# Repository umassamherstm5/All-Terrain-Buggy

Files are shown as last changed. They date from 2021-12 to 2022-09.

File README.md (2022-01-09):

# All-Terrain-Buggy
The All-Terrain Buggy is a buggy that goes on most if not all terrains. 

It is a 6-wheeled AWD remote controlled vehicle. The motors are driven by the DRV8871 motor drivers. 
The buggy is controlled via a FlySky remote that feeds PWM signals into an Adafruit Feather 328P MCU.  

This project contains the firmware for the Feather 328P and all KiCad files for the buggy's custom PCB.

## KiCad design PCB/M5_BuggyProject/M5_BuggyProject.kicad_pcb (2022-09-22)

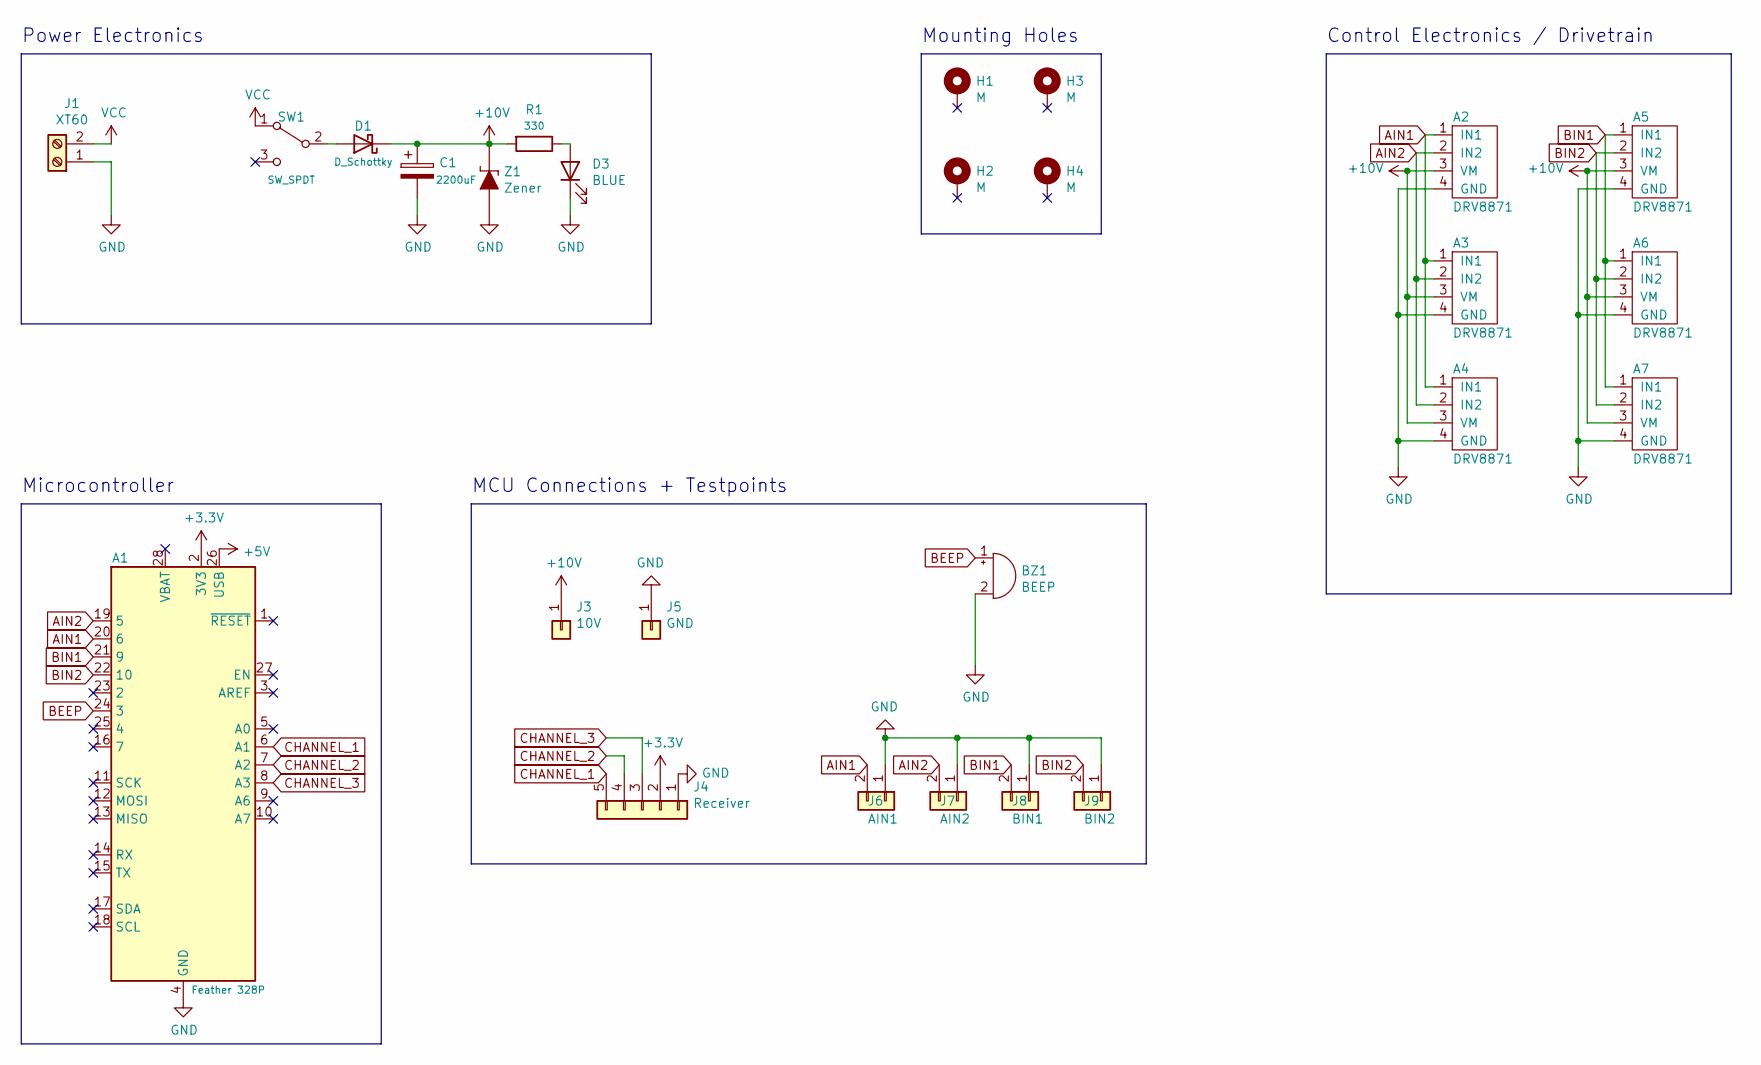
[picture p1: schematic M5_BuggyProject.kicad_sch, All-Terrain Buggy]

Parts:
A1: Feather 328P; Adafruit_Feather
A2, A3, A4, A5, A6, A7: DRV8871; PinSocket_1x04_P2.54mm_Vertical
BZ1: BEEP; Buzzer_12x9.5RM7.6
C1: 2200uF; CP_Radial_D10.0mm_P5.00mm
D1: D_Schottky; TO-220-2_Vertical
D3: BLUE; LED_1206_3216Metric
H1, H2, H3, H4: M; MountingHole_4.3mm_M4_Pad_Via
J1: XT60; AMASS_XT60-M_1x02_P7.20mm_Vertical
J3: 10V; TestPoint_Plated_Hole_D5.0mm
J4: Receiver; PinSocket_1x05_P2.54mm_Vertical
J5: GND; TestPoint_Plated_Hole_D5.0mm
J6: AIN1; PinSocket_1x02_P2.54mm_Vertical
J7: AIN2; PinSocket_1x02_P2.54mm_Vertical
J8: BIN1; PinSocket_1x02_P2.54mm_Vertical
J9: BIN2; PinSocket_1x02_P2.54mm_Vertical
R1: 330; R_1206_3216Metric
SW1: SW_SPDT; 1101M2S3CQE2
Z1: Zener; DO-214AC; MPN 1N5231BTR; Digi-Key_PN 1N5231BFSCT-ND

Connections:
+3V3: A1.2 (3V3), J4.2
+5V: A1.26 (USB)
+10V: A2.3 (VM), A3.3 (VM), A4.3 (VM), A5.3 (VM), A6.3 (VM), A7.3 (VM), C1.1, D1.1 (K), J3.1, R1.2, Z1.K
AIN1: A1.20 (6), A2.1 (IN1), A3.1 (IN1), A4.1 (IN1), J6.2
AIN2: A1.19 (5), A2.2 (IN2), A3.2 (IN2), A4.2 (IN2), J7.2
BEEP: A1.24 (3), BZ1.1 (-)
BIN1: A1.21 (9), A5.1 (IN1), A6.1 (IN1), A7.1 (IN1), J8.2
BIN2: A1.22 (10), A5.2 (IN2), A6.2 (IN2), A7.2 (IN2), J9.2
CHANNEL_1: A1.6 (A1), J4.5
CHANNEL_2: A1.7 (A2), J4.4
CHANNEL_3: A1.8 (A3), J4.3
GND: A1.4 (GND), A2.4 (GND), A3.4 (GND), A4.4 (GND), A5.4 (GND), A6.4 (GND), A7.4 (GND), BZ1.2 (+), C1.2, D3.1 (K), J1.1, J4.1, J5.1, J6.1, J7.1, J8.1, J9.1, Z1.A
unnamed: D1.2 (A), SW1.2 (B)
unnamed: D3.2 (A), R1.1
VCC: J1.2, SW1.1 (A)

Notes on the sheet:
MCU Connections + Testpoints
Control Electronics / Drivetrain
Power Electronics
Mounting Holes
Microcontroller

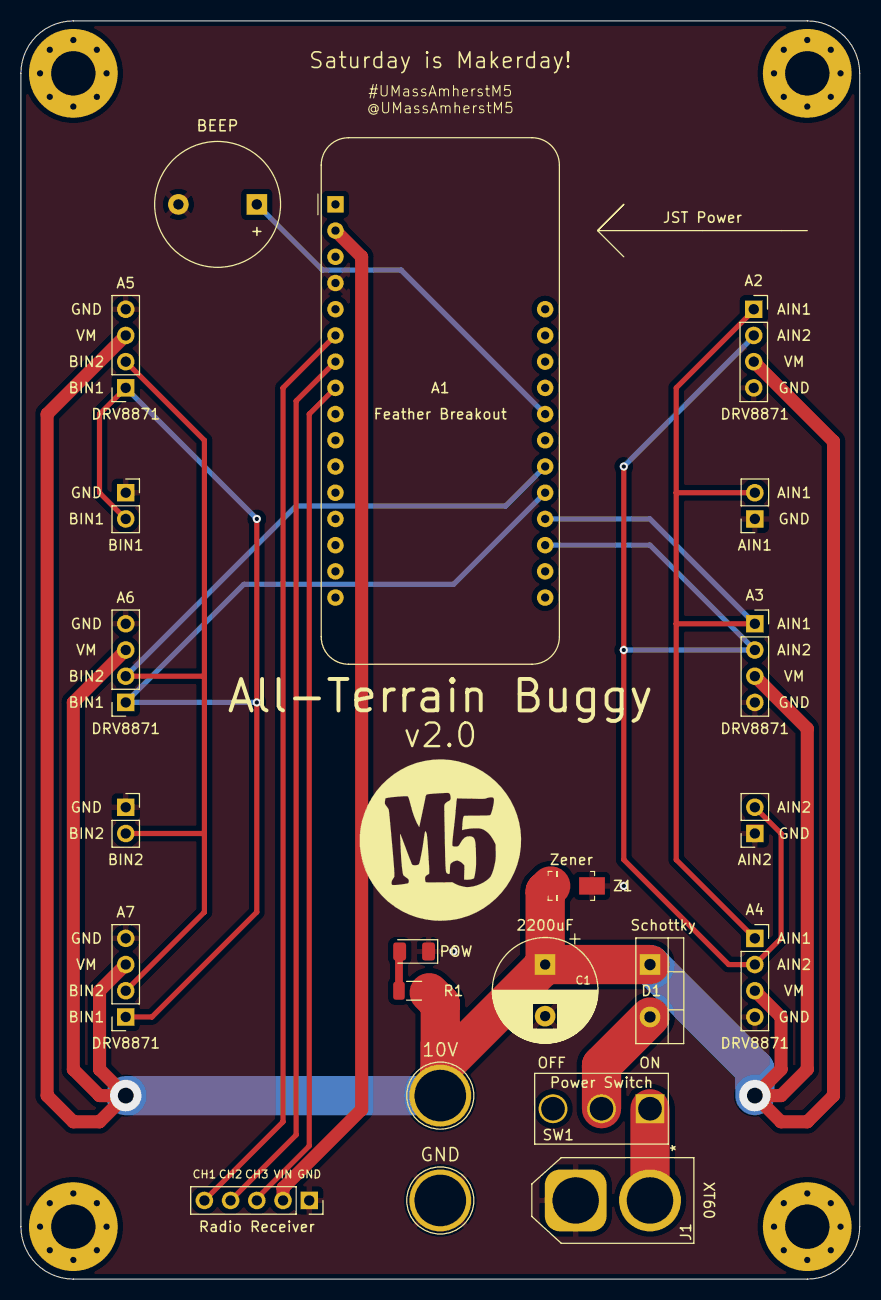
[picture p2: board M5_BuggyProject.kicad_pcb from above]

Board: 2 copper layers, 81.3 x 121.9 mm, 26 parts (0 on the bottom side), 14 nets.

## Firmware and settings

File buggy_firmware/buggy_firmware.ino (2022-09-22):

/*
 * All-Terrain Buggy
 * Firmware for interfacing with buggy and remote control 
 * Authors: Akshat Sahay, Chris Caron, Sebastian Armstrong 
 */

/*
 * FlySky FS-GT
 * ------------
 * The FlySky FS-GT is a radio receiver module which pairs to a FlySky hobbyist controller. 
 * 
 * We connect this receiver to our Feather 328P and read the pulses on different channels using the pulseIn function. 
 * CHANNEL_1 refers to the left joystick's vertical motion. 
 * CHANNEL_2 refers to the right joystick's horizontal motion. 
 * CHANNEL_3 refers to the right pot 
 */

/* pin assignments for FlySky receiver signals */
#define CHANNEL_1 A1 // controller CH2  
#define CHANNEL_2 A2 // controller CH4
#define CHANNEL_3 A3 // controller flipswitch L

/*
 * DRV8871 Motor Driver 
 * --------------------
 * The DRV8871 is a brushed DC motor driver. Two logic inputs control 4 N-channel MOFSETs for bidirectional control. 
 * The inputs can be either HIGH/LOW or PWM (we use PWM and LOW) to control motor speed and direction. 
 * Setting both inputs to LOW activates a low-power deep sleep mode. This will help us conserve battery life. 
 * 
 * For ease of control, we connect each of the 3 motors on either side of the buggy together. 
 * This allows us to use only 4 pins on the Arduino instead of 12 (2 for each motor)
 * This also makes turning easy, as we simply slow down a side to turn in either direction. 
 * In the code, we refer to A as the right side and B as the left side. 
 * 
 * All inputs are PWM-capable pins 
 * AIN1 refers to input 1 for the right side. 
 * AIN2 refers to input 2 for the right side.
 * BIN1 refers to input 1 for the left side. 
 * BIN2 refers to input 2 for the left side. 
 */

/* pin assignments for driver control signals */
#define AIN1 6
#define AIN2 5 
#define BIN1 9
#define BIN2 10 

/*
 * We use pulseIn to read the pulse durations on CHANNEL_1 and CHANNEL_2. 
 * pulseIn detects a change on a pin (LOW->HIGH/HIGH->LOW). 
 * It measures the duration of the change and returns the duration in microseconds. 
 * 
 * The receiver pulses have default durations of about 1450us for CHANNEL_1 and 1475us for CHANNEL_2.  
 * Any shorter or longer pulses mean the joysticks are being used, and the buggy needs to perform an action. 
 * 
 * The threshold values are to check for the default durations: they act as a "deadzone" when the joysticks 
 * are in their central position. The car only performs actions when the durations are more than the 
 * "deadzone" values. 
 * 
 * We organise the buggy's action into 5 modes: STOP, FORWARD, BACKWARD, LEFT and RIGHT. 
 * Speed and vertical direction are controlled by the left joystick (sig1, CHANNEL_1). 
 * Horizontal direction is controlled by the right joystick (sig2, CHANNEL_2). 
 * 
 * STOP, FORWARD and BACKWARD are simple: the car stops, goes forward or backward. 
 * LEFT and RIGHT are a little more complex: in these modes the car goes in the direction specified, 
 * but the forward and backward motion is controlled within these conditions. 
*/

/* thresholds for signal values, used for identifying action and speed */
#define SIG_HIGH_ACC 1490
#define SIG_LOW_ACC 1410

#define SIG_HIGH_STEER 1515
#define SIG_LOW_STEER 1435

#define SIG_MAX_ACC 1850
#define SIG_MIN_ACC 1100

#define SIG_MAX_STEER 1950
#define SIG_MIN_STEER 1050

#define DEBUG 0  

/* variables for incoming pulse widths from CHANNEL_1 and CHANNEL_2 respectively */
int sig1 = 0; // CHANNEL_1 value
int sig2 = 0; // CHANNEL_2 value
int beep = 0; // to BEEP or not

/* variables for speed of either side */
int a_speed = 0; // speed of right side
int b_speed = 0; // speed of left side
int offset  = 0; // speed difference for turning

/* pins for debugging and BEEP */
#define BEEP 3
#define CONFIG_R A6
#define CONFIG_L A7

/*
 * Function: setup
 * ---------------
 * Runs once at the beginning of the code (when the buggy powers up or resets). 
 * Sets all required pin modes and begins the serial module. 
 * 
 * returns: none 
 */
void setup() {
  // set RC channels to INPUT
  pinMode(CHANNEL_1, INPUT); 
  pinMode(CHANNEL_2, INPUT); 

  // set driver pins to OUTPUT
  pinMode(AIN1, OUTPUT); 
  pinMode(AIN2, OUTPUT); 
  pinMode(BIN1, OUTPUT); 
  pinMode(BIN2, OUTPUT); 

  // set debugging pins to OUTPUT
  pinMode(BEEP, OUTPUT);
  pinMode(CONFIG_L, OUTPUT);
  pinMode(CONFIG_R, OUTPUT);

  // start serial port
  Serial.begin(9600);  
}

/*
 * Function: loop
 * --------------
 * Runs every clock cycle of the ATMEGA328P (8MHz frequency). 
 * Collects pulse values from the FlySky FS-GT receiver and uses them to drive the buggy. 
 * 
 * returns: none 
 */
void loop() {
  // get signal values from receiver 
  sig1 = pulseIn(CHANNEL_1, HIGH);
  sig2 = pulseIn(CHANNEL_2, HIGH);

  if(DEBUG == 1) {
    // print signal values
    Serial.print("Signals: "); 
    Serial.print(sig1);
    Serial.print(" ");
    Serial.println(sig2);    
  }
  
  if(((sig1 < SIG_HIGH_ACC) && (sig1 > SIG_LOW_ACC)) && ((sig2 < SIG_HIGH_STEER) && (sig2 > SIG_LOW_STEER))) {
    // both signals are OFF, state: STOP
    Serial.println("OFF"); 

    // set drivers to STOP mode 
    digitalWrite(AIN1, LOW);
    digitalWrite(AIN2, LOW); 
    digitalWrite(BIN1, LOW);
    digitalWrite(BIN2, LOW); 
  }

  else if((sig1 > SIG_HIGH_ACC) && ((sig2 < SIG_HIGH_STEER) && (sig2 > SIG_LOW_STEER))) {
    // sig1 is ON, sig2 is OFF, state: FORWARD
    Serial.println("FORWARD"); 

    // limit sig1 values for speed
    if(sig1 > SIG_MAX_ACC) sig1 = SIG_MAX_ACC; 

    // get speed proportional to sig1 in FORWARD state
    // the higher the sig1 val, the higher the speed
    a_speed = map(sig1, SIG_HIGH_ACC, SIG_MAX_ACC, 0, 255);  


    // set drivers to FORWARD mode
    analogWrite(AIN1, a_speed);
    digitalWrite(AIN2, LOW); 
    analogWrite(BIN1, a_speed);
    digitalWrite(BIN2, LOW); 
  }

  else if((sig1 < SIG_LOW_ACC) && ((sig2 < SIG_HIGH_STEER) && (sig2 > SIG_LOW_STEER))) {
    // sig1 is -ON, sig2 is OFF, state: BACKWARD
    Serial.println("BACKWARD"); 

    // limit sig1 values for speed
    if(sig1 < SIG_MIN_ACC) sig1 = SIG_MIN_ACC;

    // get speed proportional to sig1 in BACKWARD state
    // the lower the sig1 val, the higher the speed
    a_speed = map(sig1, SIG_LOW_ACC, SIG_MIN_ACC, 0, 255); 

    // set driver to COUNTER-CLOCKWISE mode
    digitalWrite(AIN1, LOW);
    analogWrite(AIN2, a_speed);
    digitalWrite(BIN1, LOW);
    analogWrite(BIN2, a_speed);       
  }

  else if((sig2 < SIG_LOW_STEER) && sig2 > 0) {
    // sig1 is either ON or OFF, sig2 is ON, state: RIGHT
    Serial.print("RIGHT "); 

    if(sig1 > SIG_HIGH_ACC) {
      Serial.println("FORWARD");  

      // limit sig1 values for speed
      if(sig1 > SIG_MAX_ACC) sig1 = SIG_MAX_ACC; 
      // limit sig2 values for speed
      if(sig2 < SIG_MIN_STEER) sig2 = SIG_MIN_STEER;
  
      b_speed = map(sig1, SIG_HIGH_ACC, SIG_MAX_ACC, 0, 255); 
      offset  = map(sig2, SIG_LOW_STEER, SIG_MIN_STEER, 0, b_speed/2); 
      // to go RIGHT, left side faster than right side 
      a_speed = b_speed - offset; 
      
      // set driver to CLOCKWISE mode
      analogWrite(AIN1, a_speed);
      digitalWrite(AIN2, LOW); 
      analogWrite(BIN1, b_speed);
      digitalWrite(BIN2, LOW); 
    }

    else if(sig1 < SIG_LOW_ACC) {
      Serial.println("BACKWARD"); 

      // limit sig1 values for speed
      if(sig1 < SIG_MIN_ACC) sig1 = SIG_MIN_ACC;
      // limit sig2 values for speed
      if(sig2 < SIG_MIN_STEER) sig2 = SIG_MIN_STEER;
  
      b_speed = map(sig1, SIG_LOW_ACC, SIG_MIN_ACC, 0, 255); 
      offset  = map(sig2, SIG_LOW_STEER, SIG_MIN_STEER, 0, b_speed/2);
      // to go RIGHT, left side faster than right side 
      a_speed = b_speed - offset; 
      
      // set driver to COUNTER-CLOCKWISE mode
      digitalWrite(AIN1, LOW);
      analogWrite(AIN2, a_speed);
      digitalWrite(BIN1, LOW);
      analogWrite(BIN2, b_speed);
    }

    else {
      Serial.println("SPIN");

      // limit sig2 values for speed 
      if(sig2 < SIG_MIN_STEER) sig2 = SIG_MIN_STEER; 
      // speed dependent solely on sig2 value
      a_speed = map(sig2, SIG_LOW_STEER, SIG_MIN_STEER, 0, 255);

      // set driver to SPIN, both sides move opposite dirs
      digitalWrite(AIN1, LOW);
      analogWrite(AIN2, a_speed);
      analogWrite(BIN1, a_speed);
      digitalWrite(BIN2, LOW); 
    }
  }

  else if(sig2 > SIG_HIGH_STEER) {
    // sig1 is either ON or OFF, sig2 is ON, state: LEFT
    Serial.print("LEFT "); 

    if(sig1 > SIG_HIGH_ACC) {
      Serial.println("FORWARD"); 

      // limit sig1 values for speed
      if(sig1 > SIG_MAX_ACC) sig1 = SIG_MAX_ACC; 
      // limit sig1 values for speed
      if(sig2 > SIG_MAX_STEER) sig2 = SIG_MAX_STEER; 

      a_speed = map(sig1, SIG_HIGH_ACC, SIG_MAX_ACC, 0, 255); 
      offset  = map(sig2, SIG_HIGH_STEER, SIG_MAX_STEER, 0, a_speed/2); 
      // to go LEFT, right side faster than left
      b_speed = a_speed - offset; 
      
      // set driver to CLOCKWISE mode
      analogWrite(AIN1, a_speed);
      digitalWrite(AIN2, LOW); 
      analogWrite(BIN1, b_speed);
      digitalWrite(BIN2, LOW); 
    }

    else if(sig1 < SIG_LOW_ACC) {
      Serial.println("BACKWARD"); 

      // limit sig1 values for speed
      if(sig1 < SIG_MIN_ACC) sig1 = SIG_MIN_ACC;
      // limit sig1 values for speed
      if(sig2 > SIG_MAX_STEER) sig2 = SIG_MAX_STEER; 
  
      a_speed = map(sig1, SIG_LOW_ACC, SIG_MIN_ACC, 0, 255); 
      offset  = map(sig2, SIG_HIGH_STEER, SIG_MAX_STEER, 0, a_speed/2); 
      // to go LEFT, right side faster than left
      b_speed = a_speed - offset; 
       
      // set driver to COUNTER-CLOCKWISE mode
      digitalWrite(AIN1, LOW);
      analogWrite(AIN2, a_speed);
      digitalWrite(BIN1, LOW);
      analogWrite(BIN2, b_speed);
    }

    else {
      Serial.println("SPIN");

      // limit sig2 values for speed 
      if(sig2 > SIG_MAX_STEER) sig2 = SIG_MAX_STEER; 
      // speed dependent solely on sig2 value
      a_speed = map(sig2, SIG_HIGH_STEER, SIG_MAX_STEER, 0, 255);

      // set driver to SPIN, both sides move opposite dirs
      analogWrite(AIN1, a_speed);
      digitalWrite(AIN2, LOW); 
      digitalWrite(BIN1, LOW);
      analogWrite(BIN2, a_speed);
    }
  }

  else {
    // sig1 or 2 are 0, something went wrong 
    Serial.println("ERROR"); 
    
    // set driver to STOP mode 
    digitalWrite(AIN1, LOW);
    digitalWrite(AIN2, LOW); 
    digitalWrite(BIN1, LOW);
    digitalWrite(BIN2, LOW);
  }

  if(DEBUG == 1) {
    Serial.print("Speeds: ");  
    Serial.print(a_speed);
    Serial.print(" "); 
    Serial.println(b_speed);  
  }
}

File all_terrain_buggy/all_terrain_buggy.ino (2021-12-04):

/*
 * All-Terrain Buggy
 * M5 Demonstration 
 * Firmware for interfacing with buggy and remote control 
 * Authors: Akshat Sahay, Chris Caron, Sebastian Armstrong 
 */

/*
 * FlySky FS-GT
 * The FlySky FS-GT is a radio receiver module which pairs to a FlySky hobbyist controller. 
 * 
 * We connect this receiver to our Feather 328P and read the pulses on different channels. 
 * CHANNEL_1 refers to the left joystick's vertical motion. 
 * CHANNEL_2 refers to the right joystick's horizontal motion. 
 */

#define CHANNEL_1 A1 // channel 1 of the controller
#define CHANNEL_2 A2 // channel 2 of the controller

/*
 * TB6612FNG Dual H-Bridge
 * The TB6612FNG is a dual H-bridge motor driver which is FET based.
 * We can control its functioning using digital and analog signals. 
 * 
 * Pins AIN1 and AIN2 control motor 1 (the right side). 
 * Pins BIN1 and BIN2 control motor 2 (the left side). 
 * Pins PWMA and PWMB control the speed for each side respectively.
 * 
 * More details on its functioning on: https://learn.sparkfun.com/tutorials/tb6612fng-hookup-guide/all
 * We use the CW, CCW and STOP modes of the driver
*/

/* driver pins for TB6612, A is right and B is left */
#define AIN1 2
#define AIN2 3
#define PWMA 10

#define BIN1 5
#define BIN2 6
#define PWMB 9

/*
 * We use pulseIn to read the pulse durations on CHANNEL_1 and CHANNEL_2. 
 * pulseIn detects a change on a pin (LOW->HIGH/HIGH->LOW). 
 * It measures the duration of the change and returns the duration in microseconds. 
 * 
 * The receiver pulses have default durations of about 1450us for CHANNEL_1 and 1475us for CHANNEL_2.  
 * Any shorter or longer pulses mean the joysticks are being used, and the buggy needs to perform an action. 
 * 
 * The threshold values are to check for the default durations: they act as a "deadzone" when the joysticks 
 * are in their central position. The car only performs actions when the durations are more than the 
 * "deadzone" values. 
*/

/* thresholds for signal values, used in loop */
#define SIG_HIGH_ACC 1490
#define SIG_LOW_ACC 1410

#define SIG_HIGH_STEER 1515
#define SIG_LOW_STEER 1435

#define DEBUG 1  // print signal values

int sig1 = 0; // CHANNEL_1 value
int sig2 = 0; // CHANNEL_2 value

int a_speed = 0; // speed of A side
int b_speed = 0; // speed of B side
int offset  = 0; // speed difference for turning

void setup() {
  // set RC channels to INPUT
  pinMode(CHANNEL_1, INPUT); 
  pinMode(CHANNEL_2, INPUT); 

  // set driver pins to OUTPUT
  pinMode(AIN1, OUTPUT); 
  pinMode(AIN2, OUTPUT); 
  pinMode(BIN1, OUTPUT); 
  pinMode(BIN2, OUTPUT); 
  pinMode(PWMA, OUTPUT); 
  pinMode(PWMB, OUTPUT); 

  Serial.begin(9600); // start serial port 
}

void loop() {
  // get signal values from receiver 
  sig1 = pulseIn(CHANNEL_1, HIGH);
  sig2 = pulseIn(CHANNEL_2, HIGH);

  if(DEBUG == 1) {
    // print signal values
    Serial.print(sig1);
    Serial.print(" ");
    Serial.println(sig2);    
  }

  // states: OFF = 0, FORWARD = 1, BACKWARD = 2, LEFT = 3, RIGHT = 4 
  if(((sig1 < SIG_HIGH_ACC) && (sig1 > SIG_LOW_ACC)) && ((sig2 < SIG_HIGH_STEER) && (sig2 > SIG_LOW_STEER))) {
    // both signals are 0, state: OFF
    Serial.println("OFF"); 

    // set driver to STOP mode 
    digitalWrite(AIN1, LOW);
    digitalWrite(AIN2, LOW); 
    digitalWrite(BIN1, LOW);
    digitalWrite(BIN2, LOW); 
  }

  else if((sig1 > SIG_HIGH_ACC) && ((sig2 < SIG_HIGH_STEER) && (sig2 > SIG_LOW_STEER))) {
    // sig1 is 1, sig2 is 0, state: FORWARD
    Serial.println("FORWARD"); 

    // set driver to CLOCKWISE mode
    digitalWrite(AIN1, HIGH);
    digitalWrite(AIN2, LOW); 
    digitalWrite(BIN1, HIGH);
    digitalWrite(BIN2, LOW); 

    // limit sig1 values for speed
    if(sig1 > 1850) sig1 = 1850; 

    // get speed proportional to sig1 in FORWARD state
    // the higher the sig1 val, the higher the speed
    a_speed = map(sig1, SIG_HIGH_ACC, 1850, 0, 255); 
    analogWrite(PWMA, a_speed);
    analogWrite(PWMB, a_speed); 
  }

  else if((sig1 < SIG_LOW_ACC) && ((sig2 < SIG_HIGH_STEER) && (sig2 > SIG_LOW_STEER))) {
    // sig1 is -1, sig2 is 0, state: BACKWARD
    Serial.println("BACKWARD"); 

    // set driver to COUNTER-CLOCKWISE mode
    digitalWrite(AIN1, LOW);
    digitalWrite(AIN2, HIGH); 
    digitalWrite(BIN1, LOW);
    digitalWrite(BIN2, HIGH); 

    // limit sig1 values for speed
    if(sig1 < 1000) sig1 = 1000;

    // get speed proportional to sig1 in BACKWARD state
    // the lower the sig1 val, the higher the speed
    a_speed = map(sig1, SIG_LOW_ACC, 1000, 0, 255); 
    analogWrite(PWMA, a_speed);
    analogWrite(PWMB, a_speed);       
  }

  else if((sig2 < SIG_LOW_STEER) && sig2 > 0) {
    // sig1 is X, sig2 is 1, state: RIGHT
    Serial.print("RIGHT "); 

    if(sig1 > SIG_HIGH_ACC) {
      Serial.println("FORWARD");  
      
      // set driver to CLOCKWISE mode
      digitalWrite(AIN1, HIGH);
      digitalWrite(AIN2, LOW); 
      digitalWrite(BIN1, HIGH);
      digitalWrite(BIN2, LOW); 
  
      // limit sig1 values for speed
      if(sig1 > 1850) sig1 = 1850; 
      // limit sig2 values for speed
      if(sig2 < 1000) sig2 = 1000;
  
      b_speed = map(sig1, SIG_HIGH_ACC, 1850, 0, 255); 
      offset  = map(sig2, SIG_LOW_STEER, 1000, 0, b_speed/2); 
      // to go RIGHT, left side faster than right side 
      a_speed = b_speed - offset; 
      analogWrite(PWMA, a_speed);
      analogWrite(PWMB, b_speed);  
    }

    else if(sig1 < SIG_LOW_ACC) {
      Serial.println("BACKWARD"); 
      
      // set driver to COUNTER-CLOCKWISE mode
      digitalWrite(AIN1, LOW);
      digitalWrite(AIN2, HIGH); 
      digitalWrite(BIN1, LOW);
      digitalWrite(BIN2, HIGH); 
  
      // limit sig1 values for speed
      if(sig1 < 1000) sig1 = 1000;
      // limit sig2 values for speed
      if(sig2 < 1000) sig2 = 1000;
  
      b_speed = map(sig1, SIG_LOW_ACC, 1000, 0, 255); 
      offset  = map(sig2, SIG_LOW_STEER, 1000, 0, b_speed/2);
      // to go RIGHT, left side faster than right side 
      a_speed = b_speed - offset; 
      analogWrite(PWMA, a_speed);
      analogWrite(PWMB, b_speed);  
    }

    else {
      Serial.println("SPIN");

      // set driver to SPIN, both sides move opposite dirs
      digitalWrite(AIN1, LOW);
      digitalWrite(AIN2, HIGH); 
      digitalWrite(BIN1, HIGH);
      digitalWrite(BIN2, LOW);

      // speed dependent solely on sig2 value
      a_speed = map(sig2, SIG_LOW_STEER, 1000, 0, 255);
      analogWrite(PWMA, a_speed);
      analogWrite(PWMB, a_speed);   
    }
  }

  else if(sig2 > SIG_HIGH_STEER) {
    // sig1 is X, sig2 is -1, state: LEFT
    Serial.print("LEFT ");
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

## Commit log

2021-11-09 Added driver code
    Added code for TB6612. FORWARD, BACKWARD, and RIGHT are fully implemented.
2021-12-04 Added Documentation, Schematic
2022-01-07 Added KiCad Project, updated schematic
    [M5_BuggyProject.kicad_pcb, M5_BuggyProject.sch]
2022-01-09 Changed firmware, updated schematic and README
    [M5_BuggyProject.sch]
2022-01-11 Added updated netlist, started PCB
    [M5_BuggyProject.kicad_pcb, M5_BuggyProject.sch]
2022-01-11 Edited title blocks, netlist
    [M5_BuggyProject.kicad_pcb, M5_BuggyProject.sch]
2022-01-11 Added labels, traces for controls
    [M5_BuggyProject.kicad_pcb, M5_BuggyProject.sch]
2022-01-13 Updated PCB, added Digikey footprint library
    [M5_BuggyProject.kicad_pcb, M5_BuggyProject.sch]
2022-01-13 Added graphics to PCB
    [M5_BuggyProject.kicad_pcb]
2022-01-19 Finalised PCB for v1.0
    [M5_BuggyProject.kicad_pcb, M5_BuggyProject.sch]
2022-01-27 Added gerber files
    [M5_BuggyProject-B_Cu.gbr, M5_BuggyProject-B_Mask.gbr, M5_BuggyProject-B_Paste.gbr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]
2022-01-30 Added social logos
    [M5_BuggyProject-B_Cu.gbr, M5_BuggyProject-B_Mask.gbr, M5_BuggyProject-B_Paste.gbr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]
2022-02-02 Added connector for radio receiver
    [M5_BuggyProject.kicad_pcb, M5_BuggyProject.sch]
2022-02-03 Moved back silkscreen contents
    [M5_BuggyProject.kicad_pcb]
2022-02-10 Increased board size for trace width.
    [M5_BuggyProject.kicad_pcb, M5_BuggyProject.sch]
2022-02-12 Moved config LEDs, added OSH logo.
    [M5_BuggyProject.kicad_pcb, M5_BuggyProject.sch]
2022-02-13 Generated gerbers for v1.0
    [M5_BuggyProject-B_Cu.gbl, M5_BuggyProject-B_Mask.gbs, M5_BuggyProject-B_Paste.gbp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]
2022-03-02 Generated gerbers
    [M5_BuggyProject-B_Cu.gbl, M5_BuggyProject-B_Mask.gbs, M5_BuggyProject-B_Paste.gbp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]
2022-03-08 Updated PCB, removed gerbers
    [M5_BuggyProject-B_Cu.gbl, M5_BuggyProject-B_Mask.gbs, M5_BuggyProject-B_Paste.gbp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]
2022-04-26 Updated PCB, fixed speed thresholds in code.
    [buggy_firmware.ino]
2022-04-27 Fixed thresholds for movement
    [buggy_firmware.ino]
2022-05-18 Started PCB v2
    [M5_BuggyProject.kicad_pcb, M5_BuggyProject.sch]
2022-05-21 Added UMass logo, moved things around
    [M5_BuggyProject.kicad_pcb, M5_BuggyProject.sch]
2022-07-18 Updated PCB
    [M5_BuggyProject.kicad_pcb, M5_BuggyProject.sch]
2022-09-02 Updated document dates
    [M5_BuggyProject.kicad_pcb]
2022-09-22 Imported to KiCad 6
    We're now in KiCad 6 land.
    [M5_BuggyProject.kicad_pcb, M5_BuggyProject.kicad_sch]

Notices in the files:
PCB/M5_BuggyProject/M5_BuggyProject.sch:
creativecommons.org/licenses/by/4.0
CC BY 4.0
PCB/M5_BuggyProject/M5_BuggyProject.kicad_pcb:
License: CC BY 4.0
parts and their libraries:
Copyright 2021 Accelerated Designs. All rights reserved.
